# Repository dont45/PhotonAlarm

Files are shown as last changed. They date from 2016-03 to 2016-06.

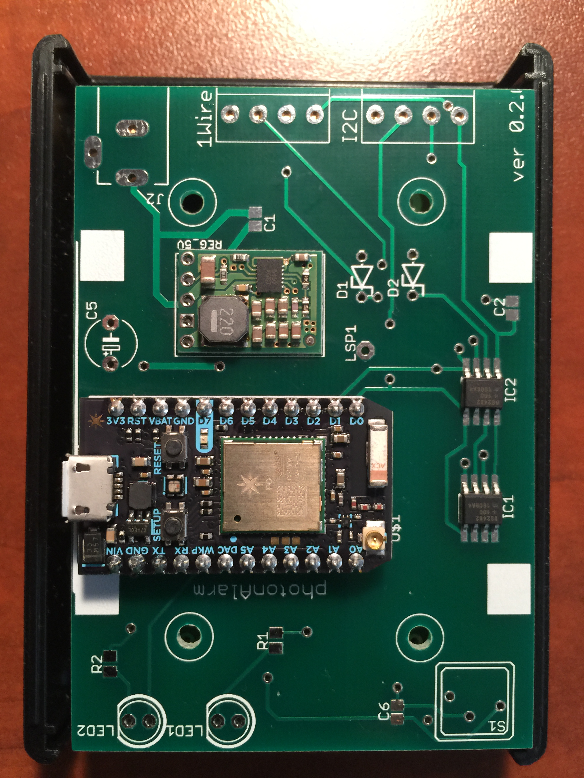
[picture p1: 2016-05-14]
photonAlarmBoardPCB.JPG

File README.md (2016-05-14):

# PhotonAlarm
A Cloud based General Alarm system based upon the Particle Photon.
The design intent is to create a small, inexpensive, flexable system to manage a wide range of sensors / detectors and provide alarm system conditioin management via an iPhone or similar device.

The current hardware in proto-type form and this software is currently running in a beta test as a storage shed alarm.  It currently has three sensors, magnetic door switch, motion detector and smoke detector.

The hardware consists of a Particle Photon, a MCP9808 precision thermometer, a DS2482 i2c to 1-wire interface, a pololu 5 volt regulator, and two status LEDs.  The three sensors are connected via the 1-wire bus, and utilize ds2406 switches connected to the actual sensor devices.

The system communicates with the 'system manager' via Pushover notification messages pushed from the Particle Cloud.  The manager communicates to the alarm system via the Particle Cloud function calls.  Currently these calls are initiated with curl but will be integrated into an iPhone management app.  Critical commands such as Disble, Enable and Alarm-State Acknowledge are securely handled via secrets.  A request for a new random 'secred' is made via the management app.  The secret is sent as an alert to the manager's phone.  This secret is then sent back to the PhotonAlarm along with the desired command.  The command is only performed if the secret matches. The secret is used only once, and times out in a few seconds.  This provides a very secure management platform even from web based messages.

The software utilizes the power of the Photon Particle build system which provides a robust c++ development environment.  The system is designed using several c++ classes and utilizes the c++ standard template library for several critical data structures, e.g. std::list for the sensor list and tripped-sensor list, and std::queue for the outgoing messages.

Currently the configuration is generated into the Photon's eeprom vi a hard-coded sensor list (writeTestConfiguration).  A future version will build a new configuration by 1) detection of a master key (1-wire iButton) at reset,  2) scanning the 1-wire bus for devices and creating the device list, and 3) assignment of name and function for each device detected via the iPhone app.  Master keys are created by having two iButton devices present at reset.  This provides a simple three-step initial (or updated) setup process.  1) Create the master keys, 2) Scan for sensors, and 3) Edit the sensor's name and function.

Currently the code contains heavy use of various debug messages via Serial.print which are enabled by a couple of #defines which will ultimately be removed in the future.

D Thompson has demo video of the companion iPhone app on YouTube:

“photonAlarm iPhone app demo” — iPhone app which monitors and manages a photonAlarm system.

Don Thompson
May 14, 2016

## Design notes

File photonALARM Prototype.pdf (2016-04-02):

# photon ALARM

## Demo at YouDoIt Electronics, Needham MA

April 2, 2016

## The Internet of Things Home Alarm

Prototype Design of a Flexible IoT Alarm and Home Monitor System

## re: Engineering March 2016

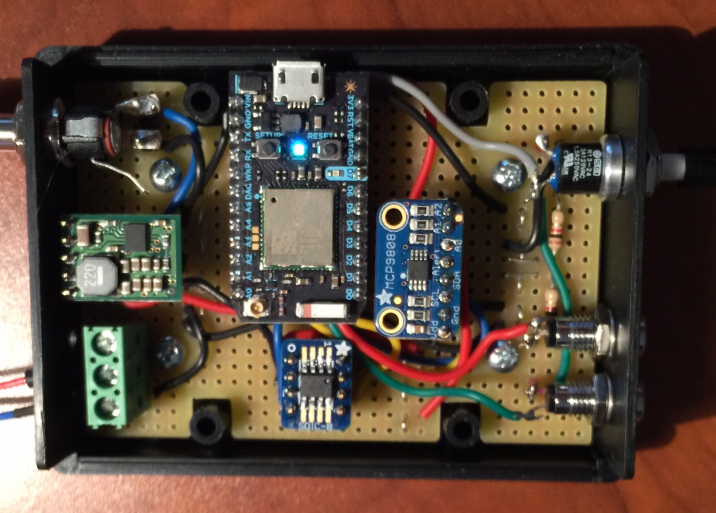
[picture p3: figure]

PHOTONALARM | PROTOTYPE | 1

# photon ALARM

## Project Description

### This project is a working prototype of a flexible, self-contained and inexpensive micro-processor system which provides a platform for various alarm and home

monitoring functions completely managed via an iPhone or other smart phone. Sensor devices are connected via a 1-Wire or I2C bus and includes temperature,

humidity, water detection, smoke alarm, motion detection and magnetic door closure. The microprocessor utilized is the Particle Photon which provides an Arduino-like environment but much more powerful since it is based upon an STM32F205 120Mhz ARM Cortex M3 processor with built 802.11b/g/n Wi-Fi (Photon) or direct cellular connect (Electron). The ARM Cortex has 1MB flash

and128KB RAM.

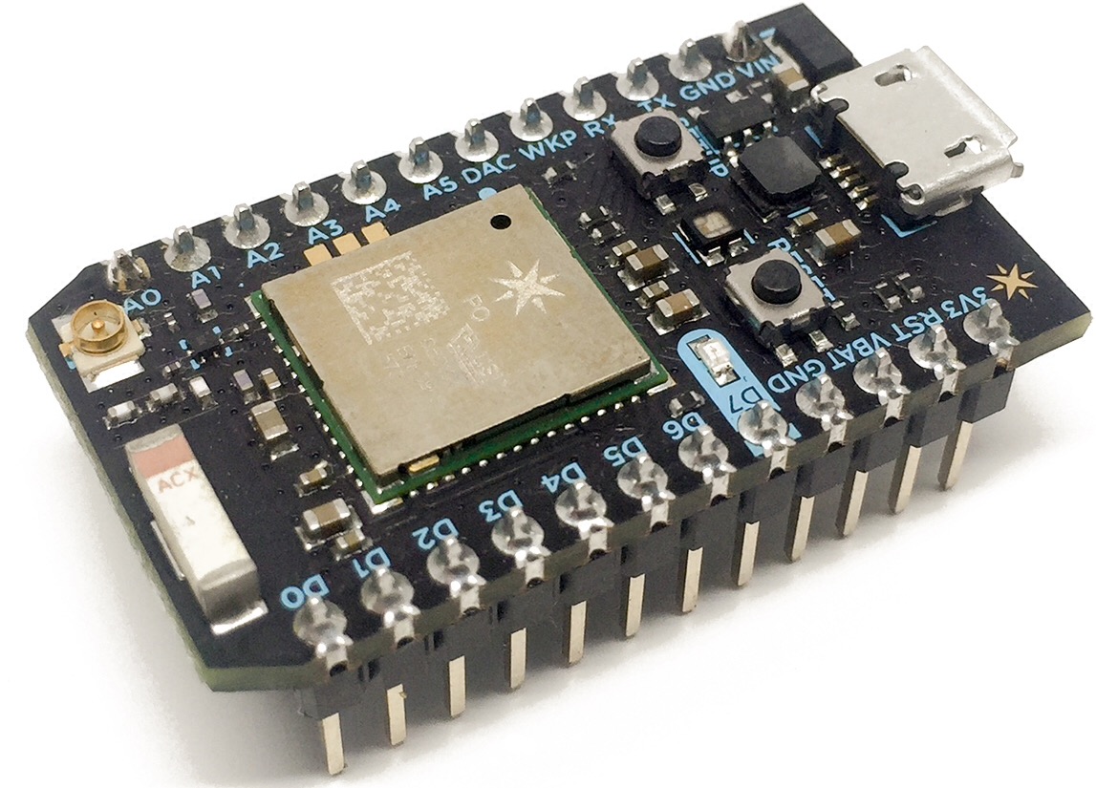
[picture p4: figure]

PHOTON

## About re: Engineering

### re:Engineering is my not-for-profit home engineering workshop with the mission of exploring the latest in hobbyist trends and technology and bringing these to useful prototypes for educational purposes. The software developed is made available to

the public via GitHub and is licensed under the GNU General Public License.

PHOTONALARM | PROTOTYPE | 2

# photon ALARM

## The Hardware

The Particle Photon processor is available at the Particle Store here for just $19. https://store.particle.io

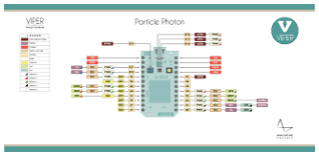
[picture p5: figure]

PARTICLE PHOTON

The sensors are connected via a DS2482-100 1-wire bridge which connects to the Photon via the I2C bus. The Arduino wire library, adapted to the Photon and the DS2482 bridge, is included in the source.

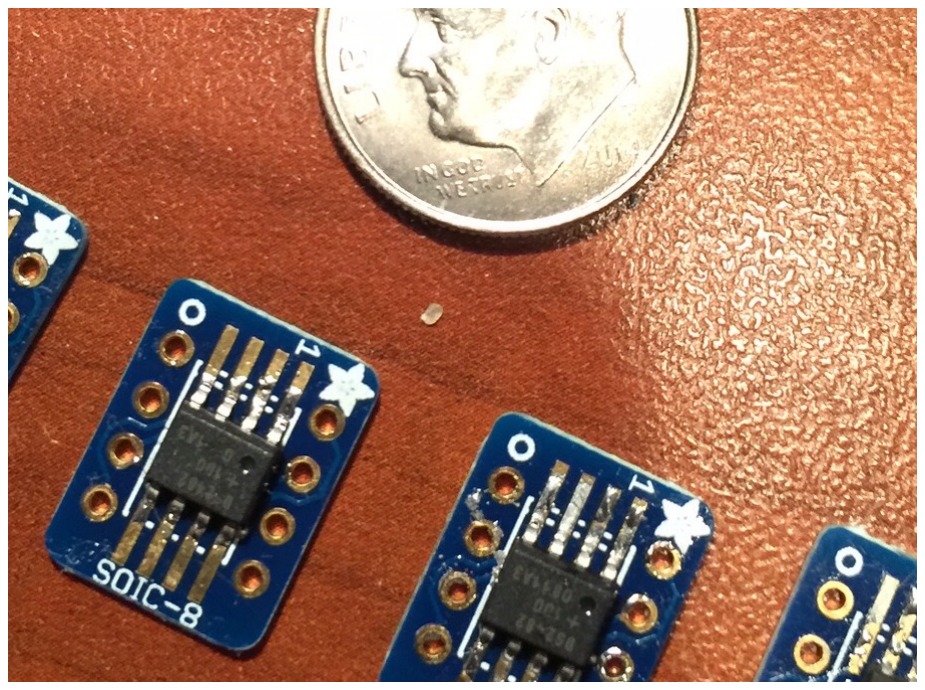
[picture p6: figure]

DS2482-100
You can learn all about 1-wire here: https://www.maximintegrated.com/en/products/digital/one-wire.htm
PHOTONALARM | PROTOTYPE | 3

# photon ALARM

Temperature can be measured with a 1-wire DS18B20 or the Adafruit MCP9807 precision temperature sensor available for $4.95 from Adafruit. The Arduino library is included in the source.

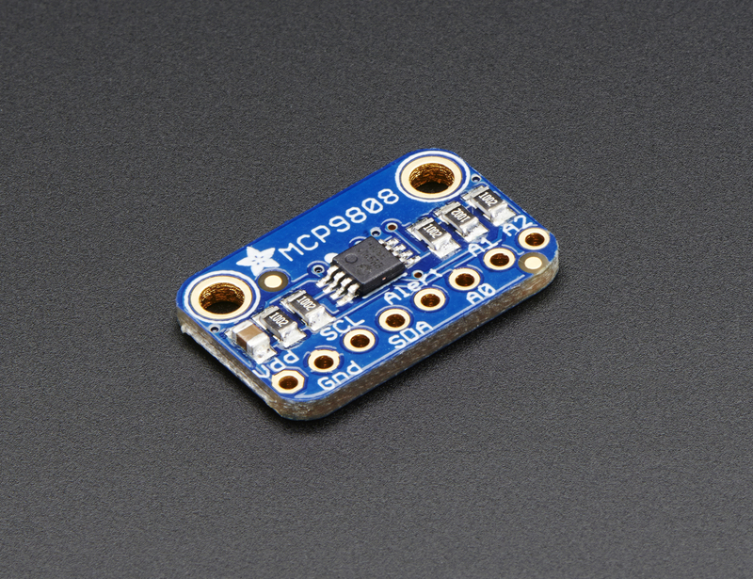
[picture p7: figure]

Power required is unregulated DC from 2.5 to 18 volts and is up/down-converted and regulated to 5 VDC via a Pololu 5V Step-Up/Step-Down Voltage Regulator S10V4F5.

### Source is available here:

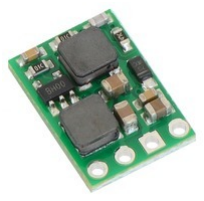
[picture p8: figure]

### https://github.com/dont45/PhotonAlarm Donald Thompson thompsondd@comcast.net

PHOTONALARM | PROTOTYPE | 4

# photon ALARM

## Alarm Operation

The primary communication of the alarm is through alerts pushed to a smart phone as shown here on an iPhone. These alerts are pushed from the photon to the phone using Pushover. Pushover is a highly reliable and secure system to easily push alerts to one or more of your smart devices including desktop computers and even with email. It is relatively inexpensive, requiring only a per device license fee of $4 which is a one-time cost for a maximum of 7500 alerts per month. You can learn all about pushover here: https://pushover.net/.

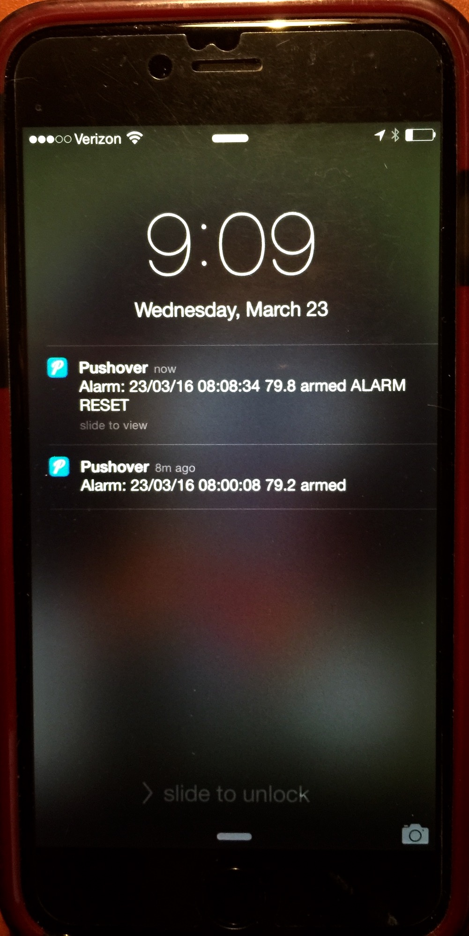
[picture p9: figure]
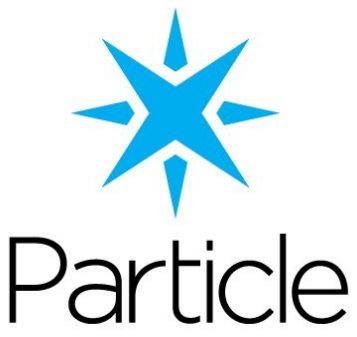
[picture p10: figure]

The following alerts are pushed to your phone:
- Alarm Alerts resulting from a tripped sensor
- State changes such as a tripped sensor now clear, or alarm disarmed.
- A periodic 'worry' alert to ensure system is operational. The time between these worry alerts can be set to 0, no worry alerts, or from 1 to 12 hours.
- Informational Alerts as a result of component failures or other unusual system events.
- Alerts as a result of user interaction with the system via an iPhone management app ( still under development) or system management web page ( temporary solution until app is available).
PHOTONALARM | PROTOTYPE | 5

# photon ALARM

## Alarm Management

All management commands which effect changes to the alarm operation, such as disabling operation, require a secret code to confirm the change. This secret code is a 4 digit random number sent via an alert and must be sent back by the user via the phone or web app to effect the change. Command execution or failure is confirmed via an alert. Management commands currently included in the prototype are:

- SET - set alarm to armed state,
- DIS - disable alarm operation,

### - ACK - acknowledge alarm condition and reset

- HOU - set number of hours between worry alerts.

### - LIST - display brief sensor devices list - UPD - send current alarm status information - RAN - send a random seed which is required for above commands

## Current Hardware

Current project hardware is an operational version built into a small project box as shown on the first page of this document and a second version assembled on a breadboard. Both will be shown at the Arduino Day event.

PHOTONALARM | PROTOTYPE | 6

# photon ALARM

## Origin, Future Projects and Ideas

This project has it's origins in an event which took place at my house 20 years ago. A water pipe froze and burst in the second floor bathroom, resulting in flooding of much of the house and massive damage. This event prompted me to build a simple alarm system using a Motorola 68HC11 micro controller with a serial port connected to a modem, programmed to read various sensors and issue messages to my pager. Similar to the current Photon model, the first version utilized Dallas Semiconductor 1-Wire devices to connect the sensors. The technology of today has advanced significantly, making it much easier and cheaper to develop more feature rich and user friendly systems.

This current project is a powerful framework for many kinds of various systems, not just alarm systems. The core technology which this system utilizes is the Particle Cloud. Communication to Pushover is done via the particle publish command, which logs the data to their cloud. This data is then easily accessible to other systems. For example, a simple nodejs script can log all of your data to a MySQL database or to Amazon's AWS. With simple changes to the software other sensor devices, such as a GPS module, can be easily added. Switching the Wifi based Photon to the cellular Electron and the system can be deployed anywhere. Just think of what you can do with this! Your summer cottage in the woods in Maine can now have a powerful system to monitor intrusion, water leaks, freezing, power outage, and anything else you can think of. No contracts, no monitoring fees, no wifi or internet required, just cellular service with a monthly cost of only $2 per month and you have complete and instant monitoring of your property.

PHOTONALARM | PROTOTYPE | 7

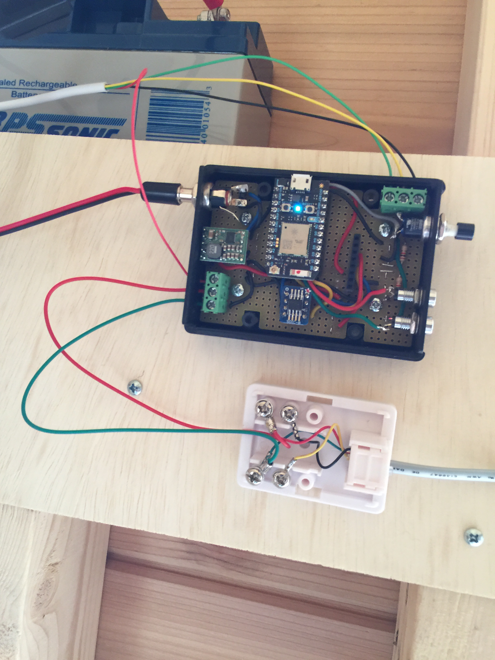
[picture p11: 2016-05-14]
photonAlarmPrototype.JPG

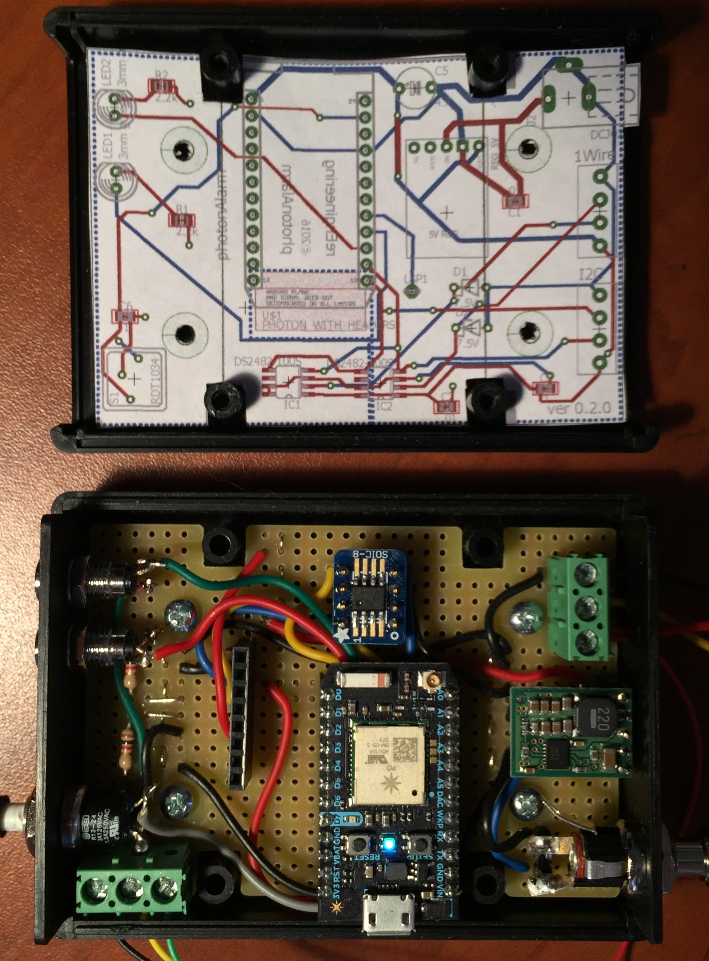
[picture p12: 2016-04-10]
photonAlarm-Boards.jpg

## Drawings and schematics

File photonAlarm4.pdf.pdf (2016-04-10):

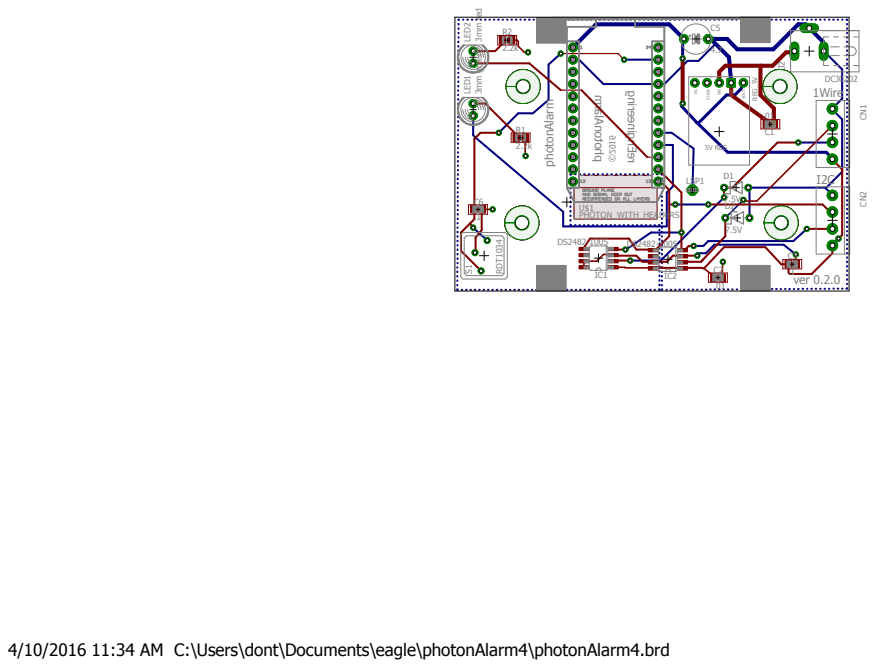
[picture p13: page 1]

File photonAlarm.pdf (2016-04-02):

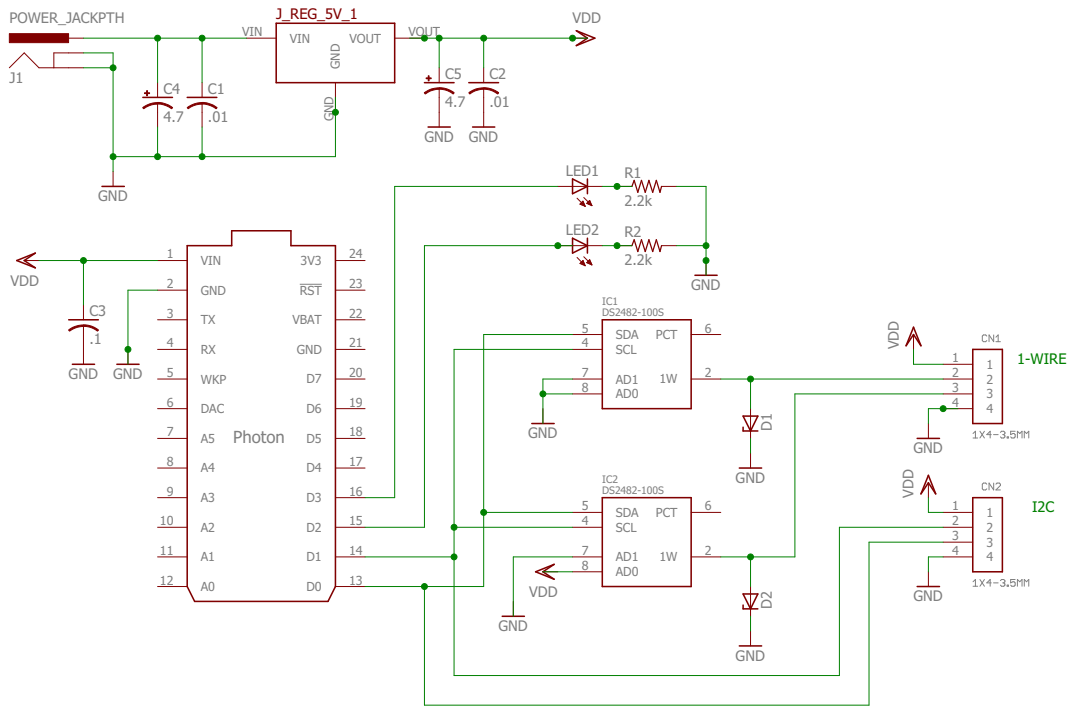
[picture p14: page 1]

Document Number: | REV:

Date: 4/2/2016 6:20 PM | Sheet: 1/1

4/2/2016 6:21 PM f=0.88 C:\Users\dont\Documents\eagle\photonAlarm\photonAlarm.sch (Sheet: 1/1)

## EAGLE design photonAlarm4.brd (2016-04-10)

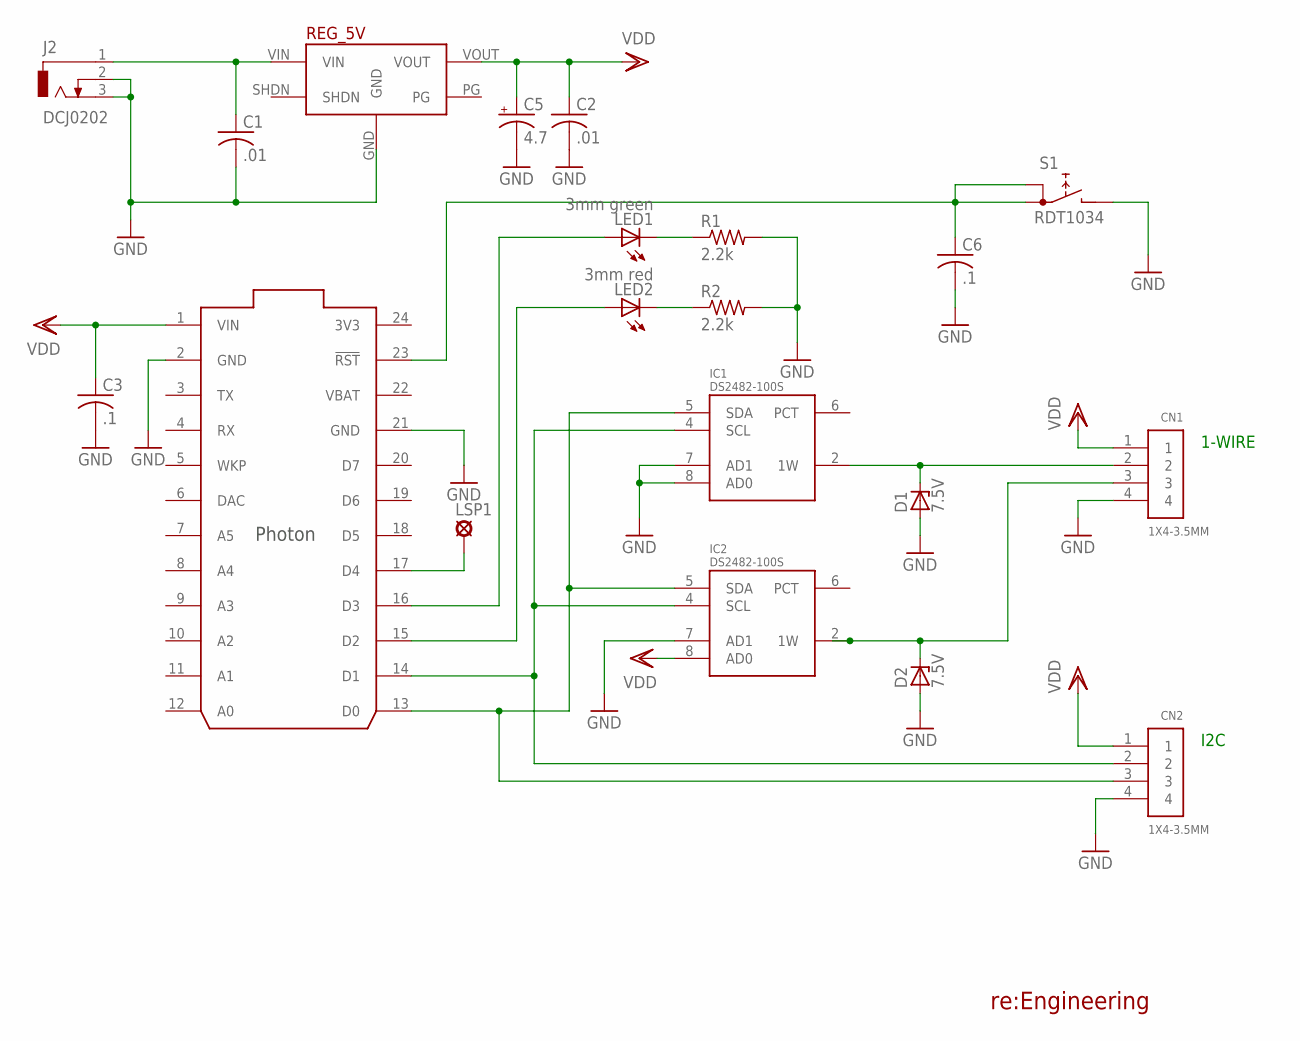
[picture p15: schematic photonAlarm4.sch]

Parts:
C1, C2: .01; C0805
C3, C6: .1; C0805
C5: 4.7; E5-6
CN1, CN2: 1X4-3.5MM; 1X04-3.5MM
D1, D2: 7.5V; ZDIO-5
IC1, IC2: DS2482-100S; SO08
J2: DCJ0202
LED1: 3mm green; LED5MM
LED2: 3mm red; LED5MM
LSP1: LSP10
R1, R2: 2.2k; M0805
REG_5V: 5V_D24V10FA; 5V_D24V10F5
S1: RDT1034
U$1: PHOTON_WITH_HEADERS; PHOTON

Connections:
3V3: U$1.24 (3V3)
GND: C1.2, C2.2, C3.2, C5.-, C6.2, CN1.4, CN2.4, D1.A, D2.A, IC1.3 (GND), IC1.7 (AD1), IC1.8 (AD0), IC2.3 (GND), IC2.7 (AD1), J2.2, J2.3, R1.2, R2.2, REG_5V.GND, S1.B, U$1.2 (GND), U$1.21 (GND)
unnamed: LSP1.MP, U$1.17 (D4)
unnamed: CN2.2, IC1.4 (SCL), IC2.4 (SCL), U$1.14 (D1)
unnamed: LED1.K (C), R1.1
unnamed: LED2.K (C), R2.1
unnamed: LED1.A, U$1.16 (D3)
unnamed: LED2.A, U$1.15 (D2)
unnamed: CN2.3, IC1.5 (SDA), IC2.5 (SDA), U$1.13 (D0)
unnamed: CN1.2, D1.C, IC1.2 (1W)
unnamed: CN1.3, D2.C, IC2.2 (1W)
unnamed: C6.1, S1.A, S1.A1, U$1.23 (!RST)
VBAT: U$1.22 (VBAT)
VDD: C2.1, C3.1, C5.+, CN1.1, CN2.1, IC1.1 (VDD), IC2.1 (VDD), IC2.8 (AD0), REG_5V.VOUT, U$1.1 (VIN)
VIN: C1.1, J2.1, REG_5V.VIN

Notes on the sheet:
I2C
1-WIRE
re:Engineering

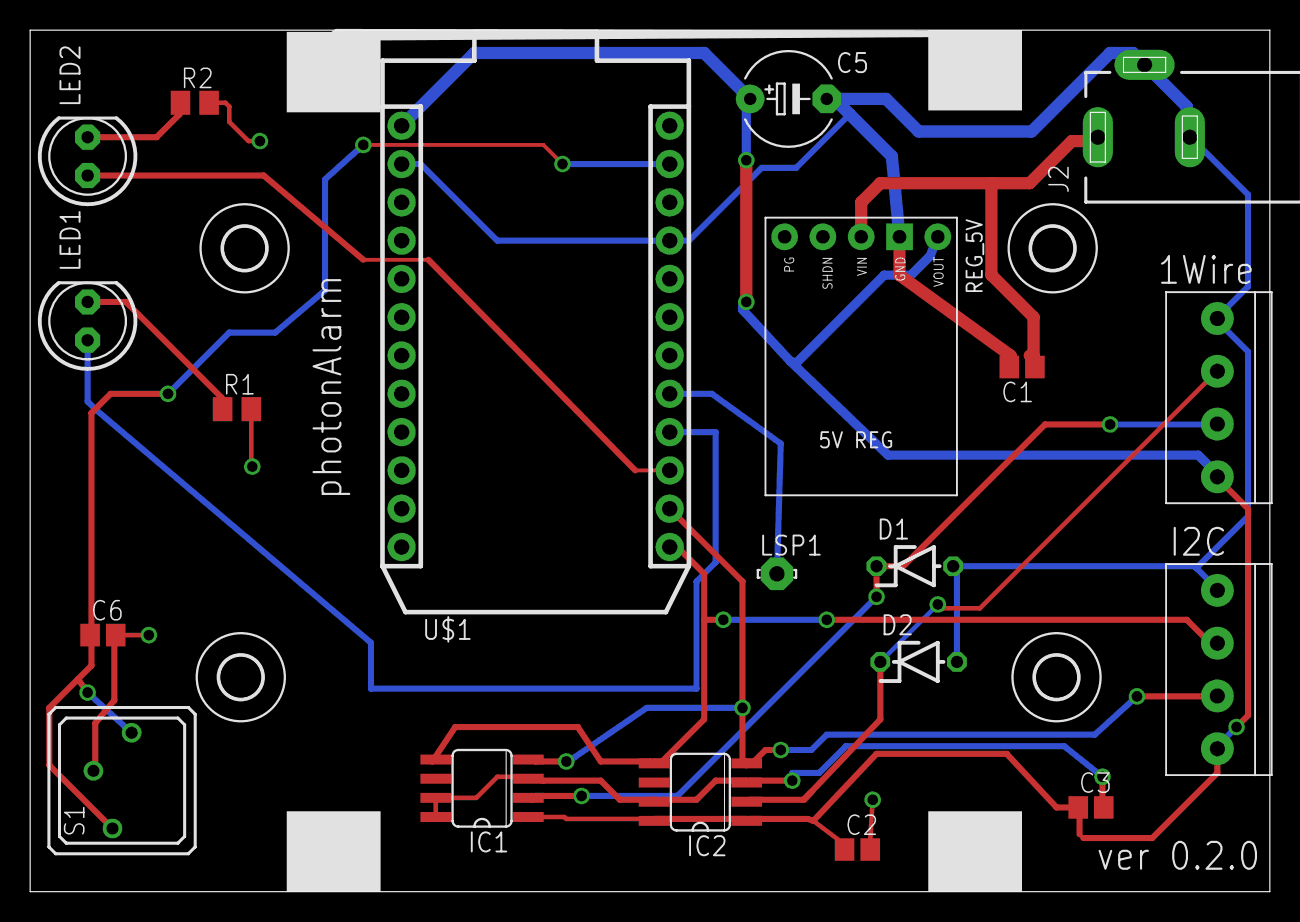
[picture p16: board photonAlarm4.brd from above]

Board: 2 copper layers, 82.2 x 57.1 mm, 24 parts (0 on the bottom side), 13 nets.

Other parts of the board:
U$2, U$3, U$4, U$5: 2,8

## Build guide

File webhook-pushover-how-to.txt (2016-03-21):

create pushover.json and add your tokens as shown
then create the particle webhook:

particle webhook create pushover.json

You should see the following output:

Sending webhook request  { uri: 'https://api.particle.io/v1/webhooks',
  method: 'POST',
  json: true,
  form: 
   { event: 'office-motion',
     url: 'https://api.pushover.net/1/messages.json',
     deviceid: undefined,
     access_token: '12341234123412341234123412341234',
     requestType: 'POST',
     headers: undefined,
     json: undefined,
     query: 
      { user: '23452345234523452345234523452345',
        token: '34563456345634563456345634563456',
        title: 'MOTION',
        message: '{{SPARK_EVENT_VALUE}}' },
     auth: undefined,
     mydevices: true } }
Successfully created webhook!

This webhook is used by class Notifier (file:Alarm-Pushover.cpp):
  Notifier(char *event_name, Sensor *s) {
    // move upd to Alarm class ???
class Notifier {
public:
...
void Notifier::sendMessage(char* msg) {
  ...
  Spark.publish(webhook_id, event_message, 60, PRIVATE);

}
// the class instance:
Notifier notify("safe-motion", &sensor);

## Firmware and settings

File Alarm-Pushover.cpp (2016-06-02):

/*
  pushover alarm system for Particle Photon
  @file     Alarm-Pushover.cpp
  @author   device_list. Thompson
  @license  GNU General Public License (see license.txt)
  @version  0.2.0

  Copyright (C) 2016 Donald Thompson, Raynham Engineering

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
  You should have received a copy of the GNU General Public License
  along with this program.  If not, see <http://www.gnu.org/licenses/>.
*/

/* TO DO:
 * Add support for hardware watchdog timer STWD100
 * Add general multi-function alarm node as sub-node (SUB_ALARM_SYSTEM)
 * This 'sensor type' will function like SUB_CAR_MONITOR except that
 * it will handle multiple alert messages.  These messages will be
 * embedded into a string to include sensor name and sensor state.
 * also need positive ack messages back.
 * How do we manage remote configuration?  Like sensor name and sensor min values?
 *
 * readSensor & checkSensor need to return more information about sensor.
 * not just a bool, or perhaps a bool and a second return value.
 *
 * alarm enable and alarm Acknowledge need to verify sensors clear before setup
 * or perhaps not?  Idea:  If you want to enable the alarm even though one sensor is
 * tripped, first disable that tripped sensor, then you can reset alarm.
 * worry notifications should show disabled sensors as a reminder.
 */

/*
 * Added in  v1.9
 * add last updated timestamp on device
 * remoteHandler to receiver car temperature alerts from sub-sensor
 * remote car sensor JUST needs to send temperature every xx minutes
 * the SUB_CAR_MONITOR device here does everything need to manage alerts
 *
 * create webhooks shed_alarm and shed_notify to utilize pushover quiet hours
 * fix oilHandler to use new Tank class (level)
 * Add priority to queued messages
 * ?? direct interacton (request and confirm) should have priority
 * worry-status is low priority
 * tank level change is low
 * each device should have an alarm-conditon priority assigned
 * therefore, tank has low but a door sensor has high
 *
 */

/* Added in v 1.8
* Add oil level to saved data and load on startup
* writre oil level to saved data on subscription receipt
 * oil level data as subscription
 * execute command then confirm with secret sent
 * Added in v 1.6
 * Sensor Id (sensor#) to device_t (array index in config_t)
 * Find by Id (in sensor LIST)
 * update to config_t at idx and write to EEPROM
 * command NAME to rename sensor (by sensor#)
 * command SEN to display all data of a sensor (by sensor#)
 * Removed short_name
 */

/* Particle Cloud published events:
 * alarmState with name of new state any time state changes
 */
// To Do:
// a) fix sysState clearing to shut off blinking Status
//    USE a timer in sysState
//    Timer ext and in class cause build to fail
// b) fix multiple notifications upon alarm condition
// d) add i-button support as key and as config management
// e) add HTU21 humidity sensor support
// f) second 1-wire buss for i-button support (clear readint)
//    or can we skip-rom to just read class 01 == i-button ??
// g) add ds thermometer support

#define SYSTEM_VERSION 0.2.1
#define SYSTEM_VERSION_MAJOR 0
#define SYSTEM_VERSION_MINOR 2
#define SYSTEM_VERSION_SUB 1

#define SERIAL_DEBUG
#define SERIAL_DEBUGXX
//#define SERIAL_WAIT
#define HARDWARE_WATCHDOG

#include "application.h"
#include <queue>
#include <list>
#include "Adafruit_MCP9808.h"
#include "OW.h"
#include "parms.h"
#include "util.h"
#include "sensor.h"
#include "math.h"
#include "stdlib.h"
#ifdef HARDWARE_WATCHDOG
#include "hwd.h"
#endif

//STARTUP(System.enableFeature(FEATURE_RETAINED_MEMORY));
//retained uint8_t testcurState;

int ledStatus = SYSTEM_STATUS_PIN;            //blink this LED at each loop pass
int ledNotice = SYSTEM_NOTIFICATION_PIN;      //blink this LED at each notification
int trigger3 = TRIGGER_PIN;
int ledStatusState = 0;
int ledStatusBlink = 0;                       // 0=solid,1=slow blink,2=fast blink
int ledStatusBlinkCount = 0;
int message_countdown = 2;
double temperatureF;                          // to publish
double gallonsO;                              // published oil gallons (demo)
double remote_temp;                           // published as temprmt
String stateA;

Adafruit_MCP9808 mcp9808;
OW ow(0);       //default 0 is 0x18 !!
// OW ow1(1);   //NO! testing second ds2483 for iButtons
// iButton ib(1);
// we SHOULD make a specific iButton class, similar to OW

#include "state.h"
State sys;

#include "tank.h"
// Tank class performs current tank content in gallons based upon
// oil level present in tank (inches of oil in tank)
Tank::Tank(uint8_t style) {
    tankStyle = style;
    volumeIN2 = 0;
    cur_gallons = 0;
    width = tank_d[style][WIDTH];
    diameter = tank_d[style][DIAMETER];
    length = tank_d[style][LENGTH];
   radius = 28 / 2;
    fullVolume();
    fullGallons();
}

// calculate inches of oil remaining in tank from sensor reading in mm
// sensor reading is from sensor at top of tank to oil surface
int Tank::calcOilLevel(int sensorReading) {
    int inchReading = sensorReading / 25;
    int sensorHeight;
    switch(tankStyle) {  //SHOULD be done int initializer
	      case VERTICAL_275:
	      case VERTICAL_330:
    	   sensorHeight = tank_d[tankStyle][DIAMETER];
	       break;
	      case HORIZONTAL_275:
	      case HORIZONTAL_330:
    	    sensorHeight = tank_d[tankStyle][WIDTH];
	      default:
	        sensorHeight = 0.0;
    }
    return sensorHeight - inchReading;
}

// calculate area of segment of curved section, bottom, top, side
float Tank::calcCurved(int lev) {
    float at;
    float a3;
    float a2;
    float a;
    float ht;
    float lt;
    float alpha;
    float alphadeg;
    float sinBeta;
    float beta;
    float betadeg;
    at = pi * radius * radius;
    ht = radius - lev;
    sinBeta = ht / radius;
    beta = asin(sinBeta);
    betadeg = beta/pi * 180.00;
    lt = cos(beta) * radius;
    a3 = ht * lt;
    alpha = ((pi/2) - beta)*2;
    alphadeg = alpha / pi * 180.00;
    a2 = ((2*pi - alpha) / (2 * pi)) * at;
    a = at - a2 - a3;
    return a;
}

// calculate volume of entire tank
int Tank::fullVolume() {
    float volEnd = pi * radius * radius * length;  //both ends
    float volMid = (diameter - width) * width * length;
    volumeIN2 = volEnd + volMid;
    return volumeIN2;
}

float Tank::fullGallons() {
    cur_gallons = volumeIN2 * CVT_IN2_GALLONS;
    return cur_gallons;
}

// level in inches, return tank volume in cubic inches
int Tank::tankVolume(int level) {
  float topVol = 0;
  float midVol;
  float botVol;
  float endVol;
  float botArea = 0.0;
  float midArea = 0.0;
  float topArea = 0.0;
  float endArea = 0.0;
  float s;
  float l;
  float fullCirc = pi * radius * radius;
  float curvedArea = 0.0; //debug
  switch(tankStyle) {
    case VERTICAL_275:
    case VERTICAL_330:
	      // end curve based upon width , i.e. 27 / 2  = 13
	      // top curve contains oil
        if( level > diameter - radius) {
	          s = diameter - width + 0;	// full straight area
	          l = diameter - level;	//??
	          botArea = fullCirc / 2.0;
	          midArea = s * width;
	          curvedArea = calcCurved(l);  //debug
            topArea = fullCirc/2.0 - calcCurved(l);
	      }
	      // top within straight section
	      else if(level >= radius) {
	          s = level - radius;
	          l = radius;
	          botArea = fullCirc / 2.0;
	          midArea = s * width;
	      }
	      // oil level in bottom curve
	      else {
	          s = 0;
	          l = level;
	          curvedArea = calcCurved(level); //debug
	          botArea = calcCurved(level);
	     }
	     midVol = midArea * length;
	     botVol = botArea * length;
	     topVol = topArea * length;
	     volumeIN2 = (int)(topVol + midVol + botVol);
	     return volumeIN2;
       break;
    case HORIZONTAL_275:
    case HORIZONTAL_330:
	     // calc curved section, use X2, one for each end
	     // calc mid section: level * w * l
	     // when level crosses half full, formula works just fine!
	     s = diameter - width;
	     midArea = level * s;
	     midVol = midArea * length;
	     endArea = calcCurved(level);
	     endVol = endArea * length;  //vol for the two ends
	     volumeIN2 = (int)(endVol + midVol);
	     return volumeIN2;
       break;
    default:
       return -1; //error
  }
  return -1;
}

float Tank::tankGallons(int level) {
   int vol_cubic_in = tankVolume(level);
   return vol_cubic_in * CVT_IN2_GALLONS;
}
#include "notifier.h"

// set sensor indicator (on PIO_A)
void Sensor::setSensorIndicator(device_t d, uint8_t indval) {
  #ifdef SERIAL_DEBUGXX
  Serial.print("setting indicator:");
  Serial.println(indval);
  #endif
  //#define PIO_A 0
  //#define PIO_B 1
  //d.port is the sensor read port
  //indicator port is the other one ??
  uint8_t indicator_port = d.port ? 0 : 1;
  #ifdef SERIAL_DEBUGXX
    Serial.print("setSensorIndicator:prot=");
    Serial.print(d.port);
    Serial.print(" indicator port=");
    Serial.println(indicator_port);
  #endif
  p_ow->writePIOtest(d.dev_rom, indicator_port, indval);  //WRITE TO PIO-x
}

// return TRUE if tripped
bool Sensor::readSensor(device_t &d) {
    uint8_t senval;
    uint8_t sensor_priority = 0;  //reporting priority
    double tempF;
    double oilL;
    bool senret;
    bool rok;
    bool toSetSensor;
    if(d.status != DEV_PRESENT) {
  #ifdef SERIAL_DEBUG
      Serial.print("Device Missing - ROM:");
      Serial.println(d.dev_rom[7],HEX);
  #endif
      return FALSE;
    }
    if(d.state == SENSOR_DISABLED) {
  #ifdef SERIAL_DEBUG
      Serial.print("Device deactivated - ROM:");
      Serial.println(d.dev_rom[7],HEX);
  #endif
      return FALSE;
    }
    switch(d.dev_use) {
      case SWITCH:    //simple switch on PHOTON pin
  #ifdef SERIAL_DEBUGXX
          Serial.print("readSensor rom=");
          Serial.print(d.dev_rom[7],HEX);
          Serial.print(" use=");
          Serial.print(d.dev_use);
  #endif
         senval = digitalRead(d.dev_rom[0]);
         d.dev_reading = (float)senval;
  #ifdef SERIAL_DEBUGXX
          Serial.print(" readvalue=");
          Serial.println(senval);
  #endif
          return senval==d.sense;
          break;
      case OW_SENSOR:
      case OW_INDICATOR:  //one-wire device on DS2482-100
          senval = p_ow->readPIOX(d.dev_rom, d.port);    //??just readPIO and use d.port
          toSetSensor = (uint8_t)d.dev_reading != senval;
          d.dev_reading = (float)senval;
          senret = senval==d.sense;
          #ifdef SERIAL_DEBUGXX
                  Serial.print("readSensor OW_SENSOR: dev_use=");
                  Serial.print(d.dev_use);
                  Serial.print(" ow value=");
                  Serial.print(senval);
                  Serial.print(" return=");
                  Serial.println(senret);
          #endif
          if(d.dev_use==OW_INDICATOR)
            //if(toSetSensor) setSensorIndicator(d, senret);
            setSensorIndicator(d, senret);
          return senret;
          break;

      case SUB_OIL_GAUGE:        //demo particle.subscribe value
              //last_oil_level is updated by subscription
              //d.dev_reading = last_oil_level;
              if(d.dev_reading < -1000.0) return FALSE;
              if(d.dev_last_read < Time.now() - DEVICE_TIMEOUT) {
                d.dev_reading = -1001.0;
                d.state=SENSOR_INACTIVE;
                return FALSE;
              }
              if(d.alert_min !=0 && d.dev_reading <= d.alert_min)
                return TRUE;
              //sensor can trip based upon notification levels
              //green condition = no notification or -1??
              //yellow condition = 0
              //red condition = priority = 1
              return FALSE;
          break;
      case SUB_CAR_MONITOR:    //sub-sensor via particle.subscribe value
              //dev_reading is updated by subscription (remoteHandler)
              // 1) temp received compared to max setting
              if(d.dev_reading < -1000.0) return FALSE;
              if(d.dev_last_read < Time.now() - DEVICE_TIMEOUT) {
                d.dev_reading = -1001.0;
                d.state=SENSOR_INACTIVE;
                //notifier.queueMessage(SHORT_HEADER,1,"Car Monitor Inactive");
                return FALSE;
              }
              if(d.alert_max !=0 && d.dev_reading >= d.alert_max)
                return TRUE;
              // 2) time-stamp of last data received
              // 3) return TRUE if alert condition
              return FALSE;     // TO DO: alert if temp < ??
          break;

      case MCP9808_THERMOMETER:  //precision thermometer on I2C
              // readTempF should use config parameters to get device info
              // i.e. i2c address etc.  This allows multiple devices on bus
              last_temp = mcp9808.readTempF();
              d.dev_reading = last_temp;
              // return value should  be tripped if outside temp range ??
              // report using priority of sensor ??
              if((int)last_temp <= d.alert_min) return TRUE;
              // readTemp should return an error condition ??
              return FALSE;
        break;
        case OW_THERMOMETER:    //ds1820 thermometer
            #ifdef SERIAL_DEBUG
              Serial.print("ds1820 testing-rom:");
              for(int i=0;i<8;i++) {
                Serial.print(d.dev_rom[i],HEX);
                Serial.print("-");
              }
              Serial.println();
            #endif
              d.dev_reading = -1.0; //debug marker ??
              rok = p_ow->readThermometer(d.dev_rom, tempF);
              if(rok) {
                d.dev_reading = tempF;
            #ifdef SERIAL_DEBUG
                Serial.print("temp Fahrenheit x100:");
                Serial.println((int)tempF*100);
            #endif
                if((int)tempF <= d.alert_min) return TRUE;
              }
              return FALSE;  //not tripped
        break;
      default:
        break;
  }
  return FALSE;
}

//REMOVE THIS...use readSensor()
float Sensor::readTemperature() {
  // last_temp should be stored by sensor,
  // part of sensor data ??
  last_temp = mcp9808.readTempF();
  return last_temp;
}

float Sensor::getLastTemperature() {
  return last_temp;
}

char* Sensor::romFormat(char *buf, uint8_t rom[]) {
  char *bp = buf;
  int n = 0;
  for(int i=0;i<8;i++) {
    bp = &buf[n];
    int rb = rom[i];
    if(rb<16) *bp++='0';
    itoa((int)rb, bp, 16);
    n+=2;
    buf[n++]='-';
  }
  buf[n-1]=0;
  return buf;
}

Sensor sensor(&ow);

// notify hours quiet hours, alarm does not
Notifier notify("shed_notice","shed_alarm", &sensor);
// Alarm states xxx  FIX:???
// need two states: alarm_state; DISARMED, armed
// and sensor_state: clear, tripped, notified
typedef enum {alarm_disarmed=0,alarm_armed=1,alarm_tripped=2,alarm_notifying=3,alarm_clearing=4};
const char* alarm_state_name_def[5] = {"Disarmed", "Armed", "Tripped", "Notify", "Clear"};


#include "alarm.h"

// lets make a special config class to handle EEPROM config
// allocate configuration with new and dealoc in destructor
// use instance of this class in Alarm routines which handle
// configuration. ???
Alarm::~Alarm(void) {
  delete p_config;
}

//scan 1-wire bus and build configuration of devices found
//preserve data (use, name, etc. ) from existing configuration
//if device was previously present
bool Alarm::generateConfiguration() {

}

//update a specific device based upon user input changes (NAME)
bool Alarm::updateConfiguration(device_t* dev, int n) {
  strncpy(configuration.name[n], dev->name.c_str(), SENSOR_NAME_SIZE);
  EEPROM_writeAnything(CONFIGURATION_ADDRESS, configuration);
}

int Alarm::clearingCount() {
  return clearing_cnt;
}

//return FALSE if some sensor still tripped
//return TRUE if all now clear
bool Alarm::clearSensorReported() {
  // run thru sensor list and clear reporting if not tripped
  // send error message if still tripped and leave reported
  std::list<device_t>::iterator k;
  bool all_clear = TRUE;
  for(k=device_list.begin(); k != device_list.end(); ++k) {
     //device_t sp = *k;
     if(k->reported) {
       if (k->tripped) {
         all_clear = FALSE;
       }
       else
         k->reported = FALSE;
     }
   }
   return all_clear;
}

String Alarm::getLastTemperature() {
  return String(sensor.getLastTemperature());
}

//typedef enum {alarm_disarmed=0,alarm_armed=1,alarm_tripped=2,alarm_notifying=3,alarm_clearing=4};
uint8_t Alarm::getState() {
  return curState;
}

// review all this (states)
bool Alarm::setState(uint8_t new_state) {
  bool result = TRUE;
  Serial.print("setState to ");
  Serial.print(alarm_state_name_def[new_state]);
  Serial.print(" :curState=");
  Serial.println(alarm_state_name_def[curState]);
  if(curState == new_state)
    return FALSE;
  // Send a publish of new alarm sate to your devices...
  stateA = String(alarm_state_name_def[new_state]);
  Particle.publish("alarmState",alarm_state_name_def[new_state],60);
  Serial.print("Published alarmState event:");
  Serial.println(alarm_state_name_def[new_state]);
  switch(new_state) {
      case alarm_disarmed:
        curState = alarm_disarmed;
        //write to EEPROM
    #ifdef SERIAL_DEBUG
        Serial.println("alarm disarmed");
    #endif
        message = "DISARMED";
        ledStatusState = 0;
        ledStatusBlink = 0;
        break;
    case alarm_armed:
        //write to EEPROM
    #ifdef SERIAL_DEBUG
        Serial.println("alarm armed");
    #endif
        // add concept of prevTripped
        if(isTripped()) {
            //fast blink status
            ledStatusBlink = 2;
            message = "NOT CLEAR";
            result = FALSE;
            break;
        }
        ledStatusState = 1;
        ledStatusBlink = 0;
        prevTripState = FALSE;
        clearing_cnt=0;
        if(isArmed())
          message = "ALARM RESET";
        else
          message = "ALARM SET";
        curState = new_state;
        break;
    case alarm_tripped:
        curState = alarm_tripped;
    #ifdef SERIAL_DEBUG
        Serial.println("alarm tripped");
    #endif
        ledStatusBlink = 1;
        prevTripState = TRUE;
        tripListString();
        message = trippedString; //??FIX
        break;
    case alarm_notifying:
        curState = new_state;
        prevTripState = FALSE;
    #ifdef SERIAL_DEBUG
        Serial.print("alarm notifying:");
        Serial.println(clearing_cnt);
    #endif
        char buf[20];
        sprintf(buf,"NOTIFYING:%d", clearing_cnt);
        message = String(buf);
        ledStatusState = 1;
        ledStatusBlink = 2;
        /*
        if(prevTripped()) {
          if(clearing_cnt > CLEARING_COUNT_MAX) { //?? count
            debug("clearing_cnt=%d\\n",clearing_cnt);
            prevTripState = FALSE;
            clearing_cnt = 0;
            setState(alarm_clearing);
          }
        }
        */
        break;
    case alarm_clearing:
        //only if sensors clear??
        message = "CLEARED";
        Serial.println("set state alarm_clearing...");
        //let user ack before setting to armed
        //setState(alarm_armed);  //recursive maybe not still armed??
        break;
    default:
    #ifdef SERIAL_DEBUG
        Serial.println("invalid status");
    #endif
        message = "INVALID ALARM STATUS";
  }
  digitalWrite(ledStatus, ledStatusState);
  return result;
}
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
void loop() {
    notify.checkTime();
  #ifdef SERIAL_DEBUG
    Serial.print(".");
  #endif
    // MAKE this all a notify function
    if(alarm1.isArmed()) {
      if(alarm1.checkSensors()) {
        // an unreported sensor is tripped
        // already know about this if alarm_tripped or alarm_notifying
        // else set state to alarm_tripped
        //typedef enum {alarm_disarmed=0,alarm_armed=1,alarm_tripped=2,alarm_notifying=3,alarm_clearing=4};
        //const char* alarm_state_name_def[5] = {"disarmed", "armed", "tripped", "notify", "clear"};
        if(!alarm1.isTripped()) {    //???? map the state moves out ??
          notify.queueMessage(FULL_HEADER,1,"sensor tripped\\n");  //TO DO: set priority based upon sensor (one with highest pri??)
          alarm1.setState(alarm_tripped);
        }
      }
      else {
        // all sensors are clear OR reported
        if(alarm1.prevTripped()) {
          //goes back to armed state by ack message or timer timeout
          //or by loop countdown ???
          alarm1.setState(alarm_notifying);
          notify.queueMessage(FULL_HEADER,1,alarm1.getPendingMessage());
        }
      }
    }
    alarm1.doStatusBlink();
    //blink2Timer.start();   // to clear blink at timeout
    notify.secret_countdown();  //timeout secret number
    if(message_countdown-- == 0) {
      notify.dequeMessage();
      message_countdown = MESSAGE_LOOP_DELAY;  // manual messages should be immediate
    }
#ifdef SERIAL_DEBUGXX
    else if(!notify.msgqueueEmpty()) {
      Serial.print("dequeMessage delayed:");
      Serial.println(message_countdown);
    }
#endif
    if(alarm1.alarmNotifying()) alarm1.clearing_countup();
    temperatureF = sensor.getLastTemperature();
    delay(LOOP_DELAY_TIME);
    //wd.checkin(); // done automatically at end of each loop
#ifdef HARDWARE_WATCHDOG
    hwd.checkin();
#endif
}

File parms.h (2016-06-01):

/* parms.h
 *
 * Configuration parameters
 */
#ifndef __PARMS_H__
#define __PARMS_H__

#define EDT_OFFSET -4
#define EST_OFFSET -5

//#define HOUSE_CONFIGURATION         //use this for HOUSE
//which configuration?  (ONLY ONE)
#define SHED_CONFIGURATION
//bench-board test configuration
#ifdef TEST_CONFIGURATION
#define MAXDEVICE 4
#define TEST_SENSOR_1
#endif
//config for HOUSE
#ifdef HOUSE_CONFIGURATION
#define MAXDEVICE 4
#define TEST_SENSOR_1
#endif
//config for neshed
//#ifdef SHED_CONFIGURATION
#define MAXDEVICE 4
//#define TEST_SENSOR_1
//#define TEST_SENSOR_2
//#define TEST_SENSOR_11
//#define TEST_SENSOR_12
//#endif

#define EE_MAGIC_CONFIG 0X40        // change this to write new test config
#define EE_MAGIC_STATE 0x9e

#define SENSOR_LIST_SCAN
#define ALERT_HOURS 3               //no longer used ??
#define LOOP_DELAY_TIME 1000        //Delay ms between loop passes
#define MAX_ALARM_NOTIFIED 1000     //Global limit on published alarms (DEBUG limit                        )
#define SYSTEM_STATUS_PIN D2        //RED if Armed, Blinking if any tripped
#define SYSTEM_NOTIFICATION_PIN D3  //GREEN blinks at each loop ??
#define TRIGGER_PIN D4              //debug pin for logic analyzer trigger
#define LOOP_SENSOR_PIN D4          //magnetic door loops
#define MOTION_LOOP_SENSOR_PIN D5   //motion detector
#define TAMPER_PIN D6               //system tamper switch loop
#define MESSAGE_PIN D7              //on-board led to show message limts reachec
#define RANDOM_MIN 1000             //range of random number for secret
#define RANDOM_MAX 9999
#define BAD_SECRET_MAX 3            //maximum bad secret tries in a row
#define PUSHOVER_SEND_MESSAGES      //actually send Pushover Messages
#define WORRY_MINUTES 5             //time between follow-up notifications
#define MESSAGE_LOOP_DELAY 1        //number of loop passes btw notifications = 5secU
#define MAX_MESSAGE_PER_HOUR 100    //absolute maximum of pushover messages per hour
#define CLEARING_COUNT_MAX 60       //no. loops passes in notifying state
#define DEVICE_TIMEOUT 1800         // HALF HOUR
#define MAX_ALLOW_OWDEV  14         //absolute maximum of ow devices
#define FMLY_IBUTTON 0x01           //NOT USED ???
#define FMLY_2405 0x05
#define FMLY_2406 0x12              //and FMLY_2407
#define FMLY_1820 0x10
#define USE_FMLY_IBUTTON
#define USE_FMLY_2405
#define USE_FMLY_2406
#define USE_FMLY_1820
#define PIO_A 0
#define PIO_B 1
#define SENSOR_NAME_SIZE 16
//#define SHORT_NAME_SIZE 2
#define ONE_DAY_MILLIS (24 * 60 * 60 * 1000)
//#define WD_EN 5                   // WatchDog enable PIN
//#define WD_WDI 6                  // WatchDog Timer Reset Input
#endif

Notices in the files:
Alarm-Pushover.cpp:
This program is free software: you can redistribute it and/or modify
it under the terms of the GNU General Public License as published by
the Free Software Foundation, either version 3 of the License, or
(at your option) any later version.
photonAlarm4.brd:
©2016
